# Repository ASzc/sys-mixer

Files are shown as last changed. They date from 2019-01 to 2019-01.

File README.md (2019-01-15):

# SYS Mixer

The SYS Mixer is a conversion board for the SYS from Schitt Audio. It turns it
into a passive line-level audio mixer, rather than switching between the inputs
in a binary manner.

The pushbutton switch selects which channel the variable resistor attenuates.
Only one channel can be attenuated at one time, due the limitations of the
SYS's default control layout.

## Bill of Materials

Components required to populate the board:

| Qty  | Part | Description |
| ---- | ---- | ---- |
| 2 | Keystone 1790-3 | PCB Standoff, 4.75mm lift, 4-40 thread |
| 1 | Alps SPUN194700 | Pushbutton Switch, 4PDT, latching |
| 1 | Alps RK09712200MC | Potentiometer, 10 kOhms, 2 gang |
| 3 | CUI RCJ-2123 | RCA Jack, two port  |
| 4 | Vishay MRS25000C1002FCT00 | Resistor, 10 kOhms, thin film, 600 mW |

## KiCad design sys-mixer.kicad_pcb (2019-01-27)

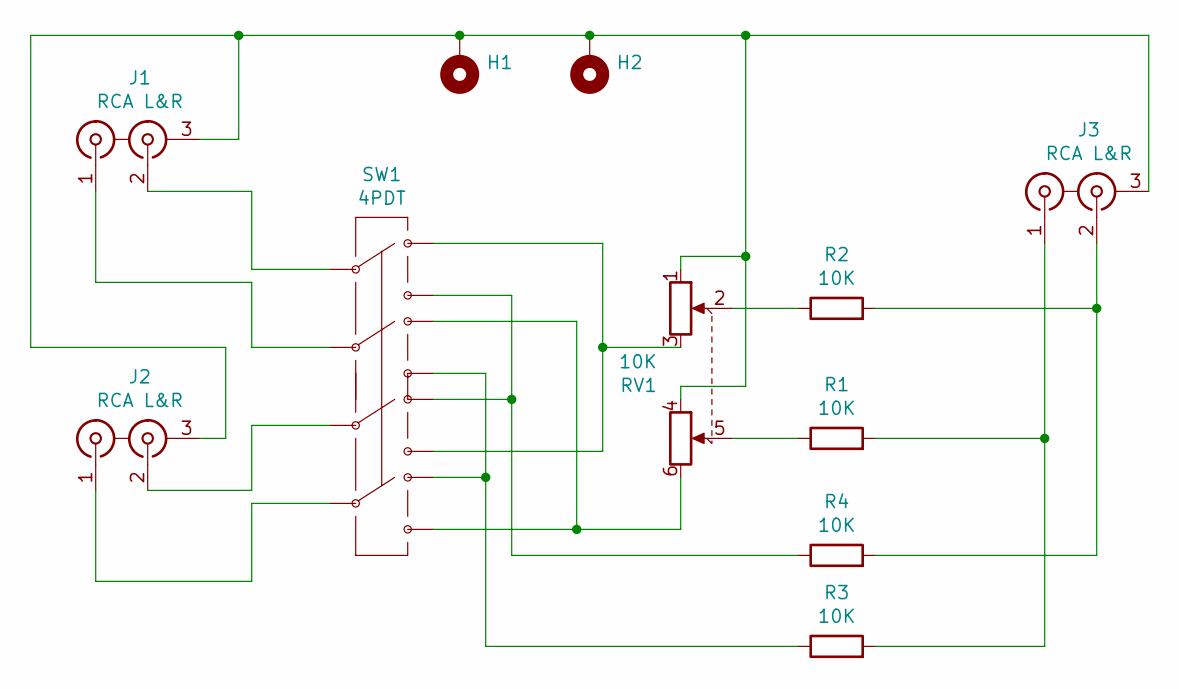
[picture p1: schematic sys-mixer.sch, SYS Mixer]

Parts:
H1, H2: MountingHole_Pad; MountingHole_4.9mm_Pad_Via
J1, J2, J3: RCA L&R; Coaxial-RCJ-2123
R1, R2, R3, R4: 10K; R_Axial_DIN0207_L6.3mm_D2.5mm_P10.16mm_Horizontal
RV1: 10K; POT-RK09712200MC
SW1: 4PDT; 4PDT-SPUN191400

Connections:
unnamed: H1.1, H2.1, J1.3 (EXT), J2.3 (EXT), J3.3 (EXT), RV1.1, RV1.4
unnamed: J1.1 (IN1), SW1.6
unnamed: J1.2 (IN2), SW1.3
unnamed: J2.1 (IN1), SW1.12
unnamed: J2.2 (IN2), SW1.9
unnamed: J3.1 (IN1), R1.2, R3.2
unnamed: J3.2 (IN2), R2.2, R4.2
unnamed: R1.1, RV1.5
unnamed: R2.1, RV1.2
unnamed: R3.1, SW1.5, SW1.10
unnamed: R4.1, SW1.2, SW1.7
unnamed: RV1.3, SW1.1, SW1.8
unnamed: RV1.6, SW1.4, SW1.11

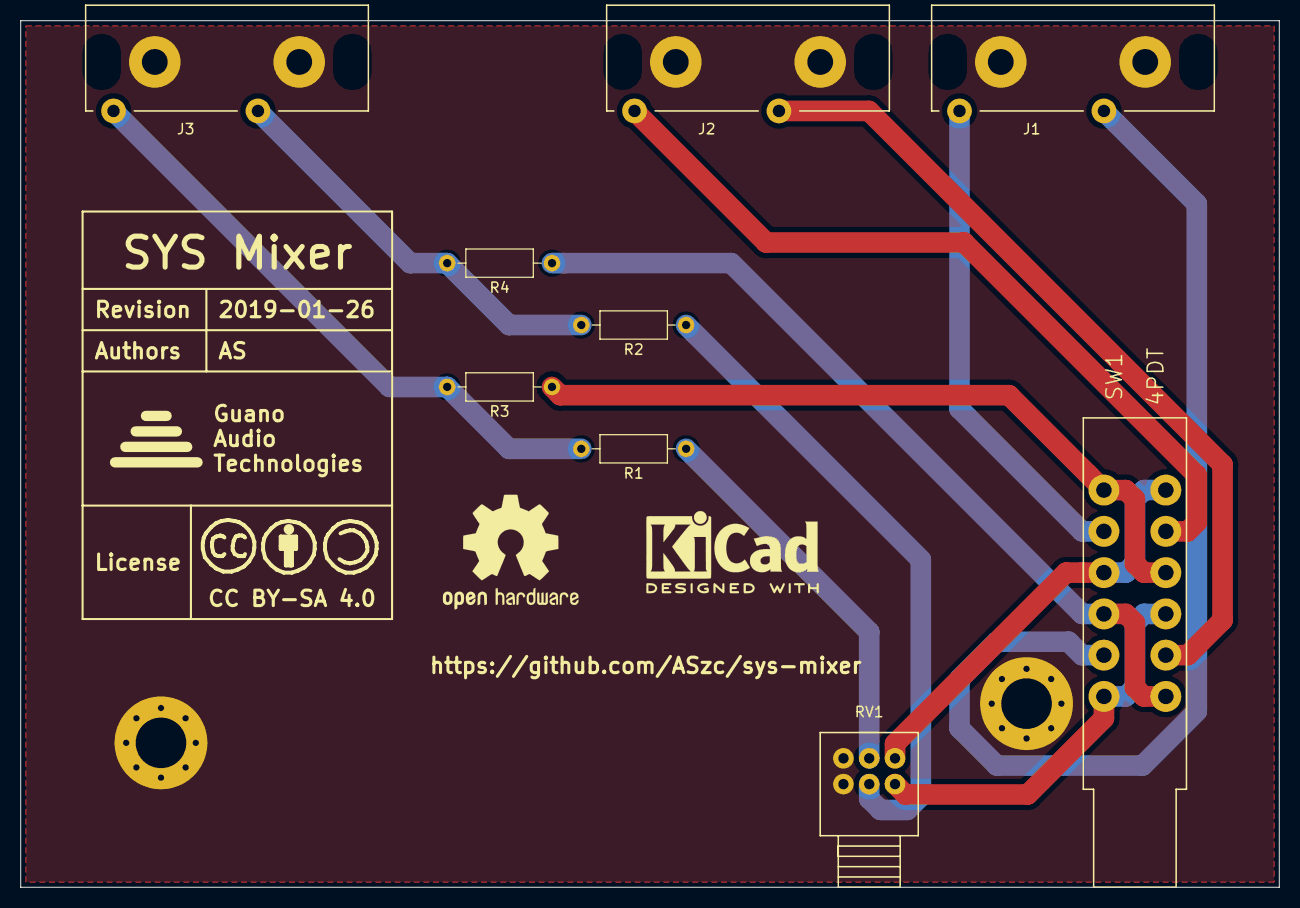
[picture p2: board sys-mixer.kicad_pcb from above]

Board: 2 copper layers, 122.0 x 84.0 mm, 11 parts (0 on the bottom side), 13 nets.

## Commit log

2019-01-15 Initial version
    [sys-mixer.kicad_pcb, sys-mixer.sch]
2019-01-15 Add github URL to silkscreen
    [sys-mixer.kicad_pcb]
2019-01-16 Reroute output so both channels are on B.Cu
    Also adjust silk info position
    [sys-mixer.kicad_pcb]
2019-01-27 Fix resistor position in schematic
    Having the resistors right after the inputs causes the mixing to
    misbehave.
    Also tweaked mounting hole and control positions, based on fitting of
    2019-01-15 boards.
    [sys-mixer.kicad_pcb, sys-mixer.sch]

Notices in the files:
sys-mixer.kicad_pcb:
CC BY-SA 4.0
